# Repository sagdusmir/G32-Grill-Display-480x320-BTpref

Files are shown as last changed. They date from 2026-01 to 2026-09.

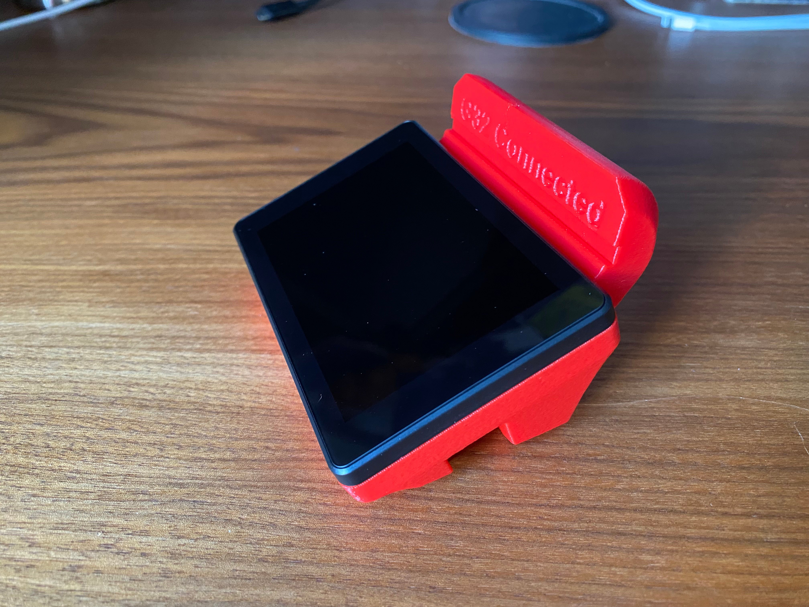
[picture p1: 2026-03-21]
misc/cases/Case JC3248W535C (remix) with mounting option to G32 or compatible modules - 7182655/images/IMG_0138.jpeg

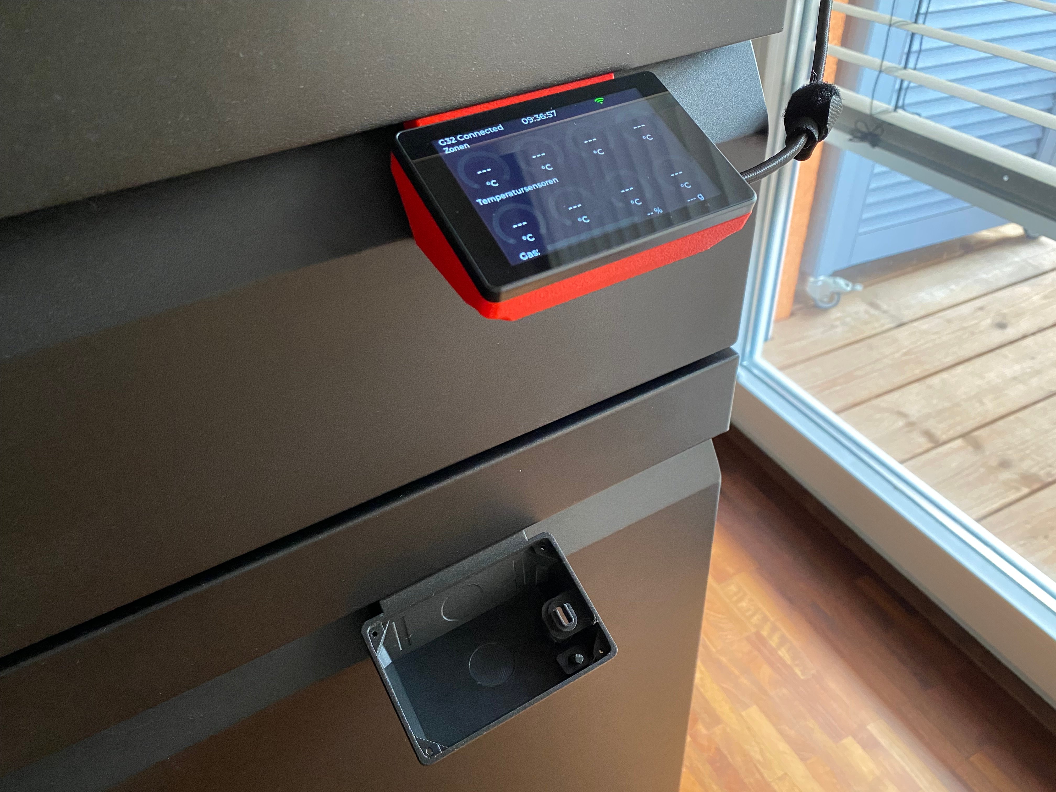
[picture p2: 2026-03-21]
misc/cases/Case JC3248W535C (remix) with mounting option to G32 or compatible modules - 7182655/images/IMG_0140.jpeg

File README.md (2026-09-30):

# G32 Connected Grill Monitor and Display








This repository started as a fork of https://github.com/JBecker32/G32-Display-480x320-BT and has since been heavily reworked with several improvements.

Focus: **mobile, cloud-independent replacement** for the official Otto Wilde app / Grill Buddy — no cloud login, no Otto Wilde servers, Home Assistant totally optional. Direct BLE connection to the grill (tested with firmware **v1.4.5**; older factory installed firmware e.g. "v13" is not compatible).

Teaser
Assembled device with the case variant for attaching it to OW Module handles.

# Table of Contents

1. [Features](#features)
   - [Implemented functionality](#implemented-functionality)  
   - [What is missing?](#what-is-missing)
   - [Limitations](#limitations)
3. [Hardware](#hardware)
   - [BOM](#bom)
   - [Component Details](#component-details)
4. [Uploading the software to the ESP](#uploading-the-software-to-the-esp)
   - [Prebuilt firmware](#prebuilt-firmware)
   - [Compile from source](#compile-from-source)
5. [FAQ](#faq)
   - [Flashing](#flashing)
   - [Usage](#usage)
6. [Impressions](#impressions)
7. [Acknowledgments](#acknowledgments)
8. [Disclaimer](#disclaimer)

## Features

### Implemented functionality

- Real-time temperatures for up to **4 grill zones** + **4 external probes**
- **Gas level** monitoring (if GasBuddy is installed)
- **Alarms** — visual + optional acoustic (buzzer/speaker) for temperature limits and timer
- **Countdown timer** with alert
- Touchscreen configuration
  - tap top-left "G32 Connected" for entering the settings screen
  - tap top-middle clock / timer to setup a countdown timer
  - tap gauges to configure a temperature alarm
- Multiple **color schemes** (predefined + easy to add your own)
- **Connection & status icons** (BLE, WiFi, lid open, light on, battery SOC)
- **Optional battery monitoring** the state of charge (SOC) of an installed internal battery can be displayed
- **Optional MEATER® integration** shows tip temperatures & battery SOC instead of G32 probes when connected. Starting with BTpref-retro2.4.6 there is an alert if temperature specs are exceeded.
- **Optional Home Assistant** connectivity that exposes most of the measurements

See [changelog.md](changelog.md).

### What is missing?
* **Meater 2 plus (aka PRO) support:** Meater 2 plus units are not supported yet
* **Gas Buddy:** calibration of a new gas bottle
* **G32 light:** setting the brightness level for turning on the light in the lid

### Limitations
* Everything that was mentioned above under [What is missing?](#what-is-missing)
* The UI might be a bit laggy at times - so touch input will take a second to have any effect. Suggestions on how to improve this further are welcome.
* Volume level of the optional buzzer / speaker is a bit low. This is the reason there is no volume control in the settings.
* Meater probes can only connect to a single device at a time. However, this does not prevent using a Meater Block.

## Hardware
### BOM

| Component | Qty | Source | Costs |
|---|-----|---|---|
| ESP32 Dev Board | 1 | Amazon, AliExpress | ~17€ - 27€ |
| Case | 1 | friend with a 3D Printer | a beer |
| Screws | 4 | hardware store, eBay, Amazon, AliExpress | ~1€ |
| Battery (optional) | 1 | Amazon, AliExpress | ~9€ | 
| Buzzer / Speaker (optional) | 1 | AliExpress, Amazon, eBay | ~2€ |
| Double-Sided mirror tape (optional)  | ? | Amazon, eBay | ~0€ |
| Connection Cable | 1 | your existing collection of cables | ~0€ |

The total cost should be around 35-40€ if you have a friend with a 3d printer. Some items might not be available individually, but only in packs of several.

### Component Details

* __ESP32 Dev Board__<br>
  You need a "__JC3248W535C__". It is equipped with an ESP32-S3, WiFi, Bluetooth, a 480x320 Pixel 3.5" touchscreen, and everything you need. No additional memory card required.

* __Case__<br>
 For a 3D model of a case for the JC3248W535C you can take a look at one of these:
   * [Case by so99hero](https://www.thingiverse.com/thing:7127557)<br>
     This nicely designed case offers enough space to fit all mentioned components and has a print-in-place mechanism to operate the power button (SW1) on the pcb.
   * [Case by so99hero (remixed by sagdusmir)](https://www.thingiverse.com/thing:7182655)<br>
     This one features minor adjustments to physically support the USB-C port and reduced clearance for the power button.<br>
     There is also a case variant that attaches directly to any front facing handles of the OW Modules which is shown in some of the images.
     If you like to have both: there is also a model that allows to hang a normal case to a OW Module handle.
   * [Case by so99hero (remixed by sagdusmir for displays prone to delamination)](https://www.thingiverse.com/thing:7295356)<br>
     This one is based on my remixed case, but features a bezel to keep the display from delaminating. The optional hanger add-on for OW Modules is also available for this model.<br>
     There is a 2nd version labeld "color-accent" that has a tiny 0.02mm recess at the front that allows you to use a Color Painting tool in your slicer ("fill" mode) and apply another filament / color to that recess.

  Note: Mounting the display to the case requires you to remove the plastic cover at the back of the display.

* __Screws__<br>
  Either M2x6mm, M2x5mm, or M2x4mm should work fine. 

* __Battery__<br>
  You can add a 3.7V LiPo/Li-Ion Battery (1 cell) with a JST 1.25 2pin connector (__watch out for correct polarity__ – see images). A capacity of 2000mAh to 3000mAh is recommended and of course it should have protection circuitry built in. This connects directly to the "BAT" (P5) connector. Maximum dimensions should not exceed 10mm x 65mm x 35mm (E.g. "103350", "103450", … "103565").

* __Buzzer / Speaker__<br>
  You can choose to connect either a buzzer or a speaker:
  * A passive piezo buzzer.<br>These do not seem to be available with a JST1.25 2pin connector. So you might need to solder a JST 1.25 2pin connector cable obtained separately to the buzzer leads. Additional work, and probably additional costs. This connects to the GPIO (P2) connector to pins IO9 and IO14. If you have a DIY JST1.25 assortment (and/or OCD), you can do a custom 8pin connector that nicely fits P2. But a 2pin connector will do fine.
  * EXPERIMENTAL: A small 8Ohm / 1W speaker (4Ohm / 3W for noisy environments) with a JST1.25 2pin connector. <br>This usually results in a slightly higher volume and a more pleasant sound. Getting one with the proper connector saves you some effort. This connects directly to the "SPEAK" (P6) connector. This is still considered "experimental" and needs some verification if the used external DAC is actually powered off if the ESP32 is powered down.

  Note: Take the available space into consideration. The passive buzzer is configured by default in the YAML. Switching to the speaker requires enabling / disabling the marked config blocks, or use a pre-configured YAML / firmware from the latest [releases](https://github.com/sagdusmir/G32-Grill-Display-480x320-BTpref/releases).

* __Cable__<br>
  Any USB-C to USB-C / USB-A with data lines will do for charging and flashing the ESP32.

* __Double-Sided mirror tape__<br>
  Use this to hold the battery and buzzer / speaker in place.

## Uploading the software to the ESP

### Prebuilt firmware

Each [GitHub Release](https://github.com/sagdusmir/G32-Grill-Display-480x320-BTpref/releases/latest) includes compiled images with placeholder Wi-Fi, OTA, and Home Assistant values. The extra `.espbinpatch` suffix is the same firmware as a `.bin` — patch those secrets, then flash. Do not flash the download as-is.

| File | When to use |
|---|---|
| `*-buzzer.factory.bin.espbinpatch` | Buzzer hardware, first flash on a new or empty board (erases everything) |
| `*-buzzer.ota.bin.espbinpatch` | Buzzer hardware, later updates if the device already works (keeps saved settings) |
| `*-speaker.factory.bin.espbinpatch` | Speaker hardware, first flash on a new or empty board (erases everything) |
| `*-speaker.ota.bin.espbinpatch` | Speaker hardware, later updates if the device already works (keeps saved settings) |

1. Download the matching file from the latest release.
2. Use the ESP Bin Patcher link in the release notes (preconfigured) in **Chrome or Edge**.
3. Choose the downloaded file on that page.
4. Fill in the replacements (Wi-Fi SSID, Wi-Fi password, OTA password, Home Assistant API key).
   For the API key, paste your Home Assistant / ESPHome `api.encryption.key` (the Base64 value) as **New**.
5. Click **Patch firmware**, connect the board via USB, then **Install patched firmware**.
   - Factory file: choose **Erase everything**.
   - OTA file: choose **Keep saved settings**.

### Compile from source

1. Install ESPHome CLI
   ```bash
   pip install esphome
   ```
2. Clone this repository and change directory into that folder
   ```bash
   git clone https://github.com/sagdusmir/G32-Grill-Display-480x320-BTpref.git && cd G32-Grill-Display-480x320-BTpref
   ```
3. Connect the JC3248W535C via USB
4. Compile and flash the software
   ```bash
   esphome run g32-display.yaml
   ```
   You may be asked how the connection should be established.

## FAQ

### Flashing

1. Easiest path: download a prebuilt `.espbinpatch` from the latest [release](https://github.com/sagdusmir/G32-Grill-Display-480x320-BTpref/releases/latest) and patch Wi-Fi / OTA / Home Assistant values in [ESP Bin Patcher](https://sagdusmir.github.io/ESP-bin-patcher/) (see [Prebuilt firmware](#prebuilt-firmware)). If you compile from source: nothing to change in the YAML if you trust everyone on the same WiFi. Everyone else: `api_encryption_key`, `ota_password`. Have a look at the very top of `g32-display.yaml` for details.

2. During validation of the yaml file, you might see something like `[max_connections] is an invalid option for [esp32_ble]`. The "max_connections" option has been moved from "esp32_ble_tracker:" to "esp32_ble:". Both variants are included in the YAML and you need to switch to the other variant by adding / removing a comment (#). Do not mess up the indentation. This is caused by a breaking change in esphome.

3. If compiling and flashing the ESP32 succeeds, but the screen is looking distorted (the left portion is partially readable while the right portion shows mostly pixel noise"), simply look at the "dimensions" in the "display" section and swap the values for "width:" and "height:". This is caused by a breaking change in esphome.

4. If you get A LOT of strange syntax errors, try to clean up the configured build folder via
   ```bash
   esphome clean g32-display.yaml
   ```

### Usage
   - How do I know the current IP address if the device is connected to WiFi? Open "Settings" and touch the tiny version text in the title bar. Next to the QR code there should be the current IP address displayed.
   - Why does the device power on if the USB power supply is removed? That is expected behavior of the used Dev-Board and happenes due to switching from USB power supply to battery power supply.
   - Why is the battery SOC incorrect if the device is powered via USB? The onboard charge contoller has no I²C interface to get any information about the supplied power and progress of charging. The shown SOC during charging is not accurate.
   - Why can the device not be powered off during charging? This is a hardware limitation of the used Dev-Board due to how charging is handled.
   - Why is my device losing battery charge when not in use? The Dev-Board seems to always draw a noticable amount of power - even if the device is shut down. There is no easy fix for that.
   - Why does the device not power off, even if I press the power button for a few seconds? Try to press the button even longer. This can take up to 14 seconds and varies from device to device.

## Impressions
<small>These images show different versions of the software - so some details might be inconsistent.</small>

device_assembly
BTpref-retro2 0 0-main_view_cyan

BTpref-retro2 0 1-main_view_red_light
BTpref-retro2 0 1-main_view_white
BTpref-retro2 0 0-main_view_amber
BTpref-retro2 0 0-temp_alarm
BTpref-retro2 0 0-timer
BTpref-retro2 0 0-mac_address
BTpref-retro2 3 0-wifi
BTpref-retro2 4 3-options
BTpref-retro2 3 1-warnings
BTpref-retro2 2 0-display
BTpref-retro2 0 0-meater
BTpref-retro2 4 3-version
BTpref-retro2 4 0-reduced-temp-alarm-info
Speaker Assortment
BTpref-retro2 4 1-battery-3000mAh
device_assembly_4ohms
In action 1
In Action 2
JC3248W535 board

## Acknowledgments
This project would not have been possible without the work of the community. Special thanks go to:

[JBecker32/G32-Display-480x320-BT](https://github.com/JBecker32/G32-Display-480x320-BT) (the original software project)

[fschwarz86/g32](https://github.com/fschwarz86/g32)

[ralmoe/g32-docker-client](https://github.com/ralmoe/g32-docker-client)

[MortenVinding/MEATER.yaml](https://gist.github.com/MortenVinding/a513c0094d0df41a4425612257b3cabc) (Meater® accuracy)

[so99hero/Standalone Case JC3248W535C](https://www.thingiverse.com/thing:7127557)

## Disclaimer
This is third-party software developed by the community and is not officially developed or supported by Otto Wilde GmbH. Use at your own risk.

__This project is provided for educational and experimental purposes only.__

All hardware designs, schematics, code, instructions, and documentation are offered AS IS without any warranty of any kind, express or implied.
YOU BUILD AND USE THIS AT YOUR OWN RISK.
The author(s) and any contributors are not responsible for any injury, death, property damage, fire, electrical shock, data loss, voided warranties, legal violations, or any other consequences — direct, indirect, incidental, or consequential — that may result from building, modifying, or using this project or any derivative work.
Always follow local electrical/safety/building codes.

If you're not experienced with mains voltage, high current, lithium batteries, lasers, moving parts, etc., consult a qualified professional before proceeding.
Proceed only if you accept full personal responsibility.

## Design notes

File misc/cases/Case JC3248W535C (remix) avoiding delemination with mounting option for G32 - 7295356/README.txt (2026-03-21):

Case JC3248W535C (remix) avoiding delemination with mounting option for G32 by sagdusmir on Thingiverse: https://www.thingiverse.com/thing:7295356

Summary:
Remixed remix case for the ESP32S3 3.5" touchscreen module JC3248W535C.Original model: https://www.thingiverse.com/thing:7127557Remixed model: https://www.thingiverse.com/thing:7182655 IF your JC3248W535C display tends to lift off the plastic carrier (due to bad adhesion), this model is for you!If not: go with one of the original designs instead. :)The ESP32 dev board module is secured with four M2x4 mm, M2x5 mm, or M2x6 mm threaded screws.There are 3 different designs available:The remix case remixed with minor changes:there is an additional bezel that clips to the ESP32 display and prevents the top display from separatingA hanger that serves as an add-on for the case  (only intended to be used with this case model because it takes the added bezel into consideration).In case you happen to own a G32 Connected gas grill, this repository might be of interest to you: https://github.com/sagdusmir/G32-Grill-Display-480x320-BTprefIMPORTANT:- Do not print with supports!- You might need to drop the bottom of the model onto the print bed in your slicer - Before installing the display, the cover plate on the back of the display must be removed!- Before tightening down the screws, check if the collar around the USB-C port causes any distress to the PCB or its components!  (the display detaches from  its mounting frame if there is any force applied from the back by the case)

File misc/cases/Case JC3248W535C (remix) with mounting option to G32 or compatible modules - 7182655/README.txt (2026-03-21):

Case JC3248W535C (remix) with mounting option to G32 or compatible modules by sagdusmir on Thingiverse: https://www.thingiverse.com/thing:7182655

Summary:
Remixed case for the ESP32S3 3.5" touchscreen module JC3248W535C.Original model: https://www.thingiverse.com/thing:7127557 If your displays tends to lift itself off the plastic carrier, check this out: https://www.thingiverse.com/thing:7295356 The ESP32 dev board module is secured with four M2x4 mm, M2x5 mm, or M2x6 mm threaded screws.There are 3 different designs available:The original case remixed with minor changes:The clearance for the button was reduced by about 0.3mm (less force required to operate the button).Added collar around the USB-C port to hold down the PCB and prevent flex if the USB-C plug is removed.The remixed case what can be hooked into any G32 Connected handles or the handles of compatible modules (this is an alternative ESP32 case)A hanger that serves as an add-on instead of a replacement for the case  (compatible with the original case or the remixed one).In case you happen to own a G32 Connected gas grill, this repository might be of interest to you: https://github.com/sagdusmir/G32-Grill-Display-480x320-BTprefIMPORTANT:- Do not print with supports!- You might need to drop the bottom of the model onto the print bed in your slicer - Before installing the display, the cover plate on the back of the display must be removed!- Before tightening down the screws, check if the collar around the USB-C port causes any distress to the PCB or its components!  (the display detaches from  its mounting frame if there is any force applied from the back by the case)Updates2026-02-12 The case with the included hanger has been updated for easier printing and offers slightly more space for internal components.

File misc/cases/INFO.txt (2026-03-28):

This is a BACKUP of my case models on Thingiverse in case the platform goes the way of the Dodo.

Please always give preference to the online versions and only see this as a fallback.

Printing instructions: All 3D models in this repo can be printed whithout support. Orient the bottom (for the bezel model only: the top) on the build plate and you should be good to go.

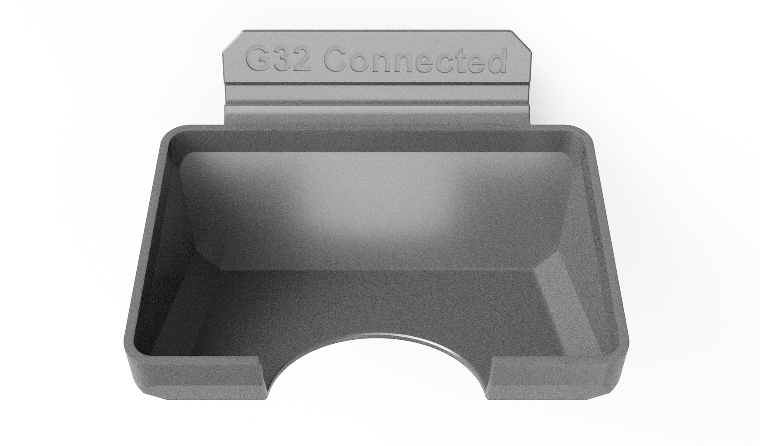
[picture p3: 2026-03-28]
misc/cases/Case JC3248W535C (remix) with mounting option to G32 or compatible modules - 7182655/images/Case_JC3248W535C_optional_hanger.jpg

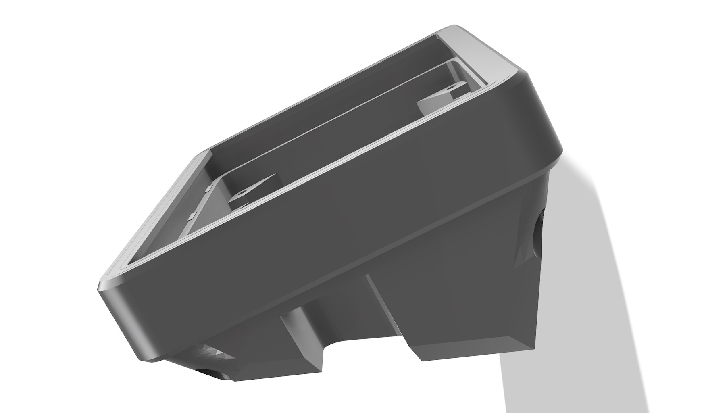
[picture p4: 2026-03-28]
misc/cases/Case JC3248W535C (remix) avoiding delemination with mounting option for G32 - 7295356/images/Case_JC3248W535C_for_use_with_bezel.jpg

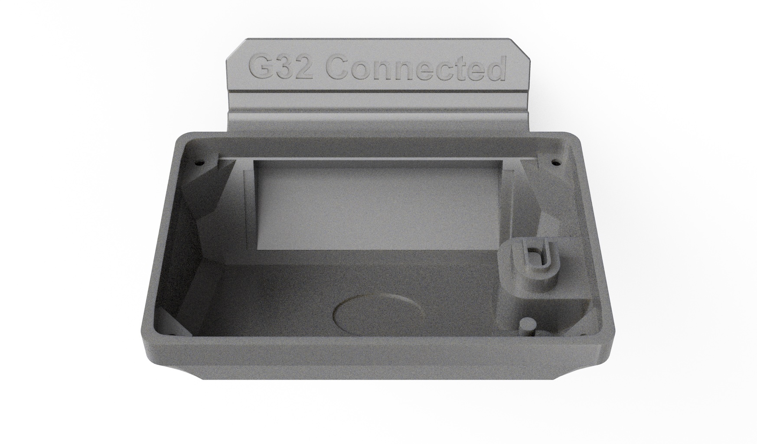
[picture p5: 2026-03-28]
misc/cases/Case JC3248W535C (remix) with mounting option to G32 or compatible modules - 7182655/images/Case_JC3248W535C_for_G32_-_gravity_hanger.jpg

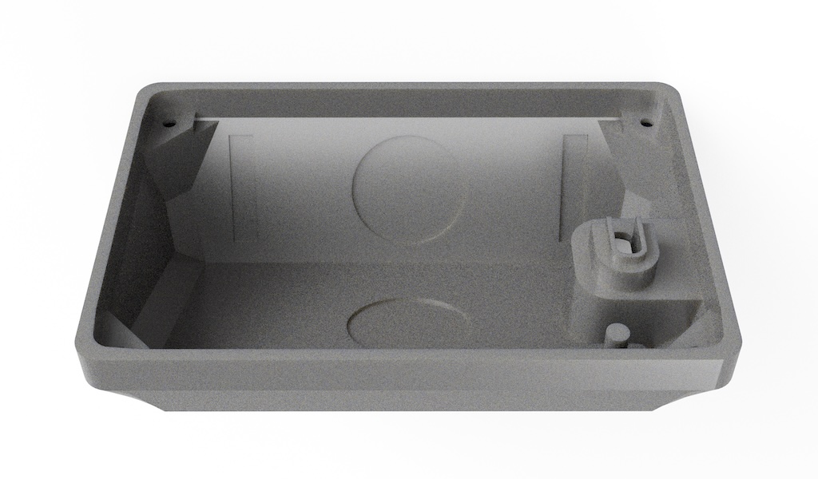
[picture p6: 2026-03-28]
misc/cases/Case JC3248W535C (remix) with mounting option to G32 or compatible modules - 7182655/images/Case_JC3248W535C_mod.jpg

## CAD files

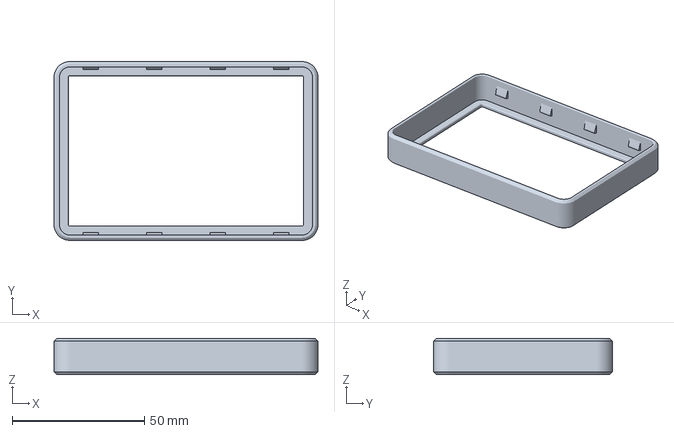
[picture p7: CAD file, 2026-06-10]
misc/cases/Case JC3248W535C (remix) avoiding delemination with mounting option for G32 - 7295356/files/Case_JC3248W535C_bezel-color-accent.3mf
99.8 x 67.6 x 13.7 mm

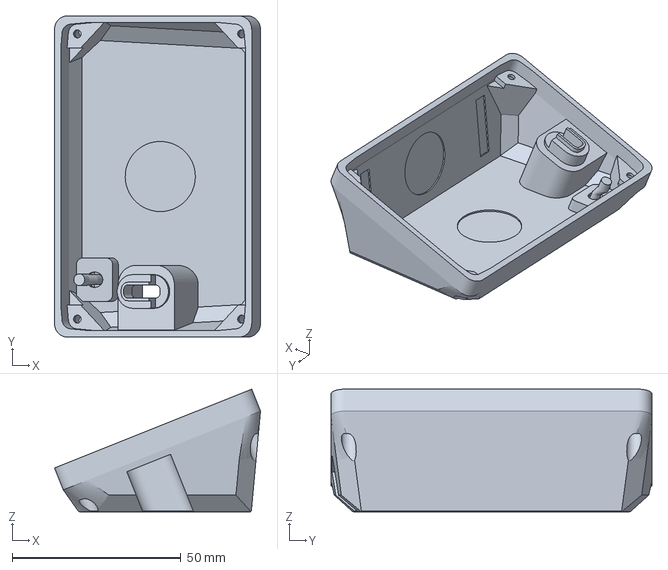
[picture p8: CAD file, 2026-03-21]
misc/cases/Case JC3248W535C (remix) with mounting option to G32 or compatible modules - 7182655/files/Case_JC3248W535C_mod.3mf
61.1 x 95.2 x 36.4 mm

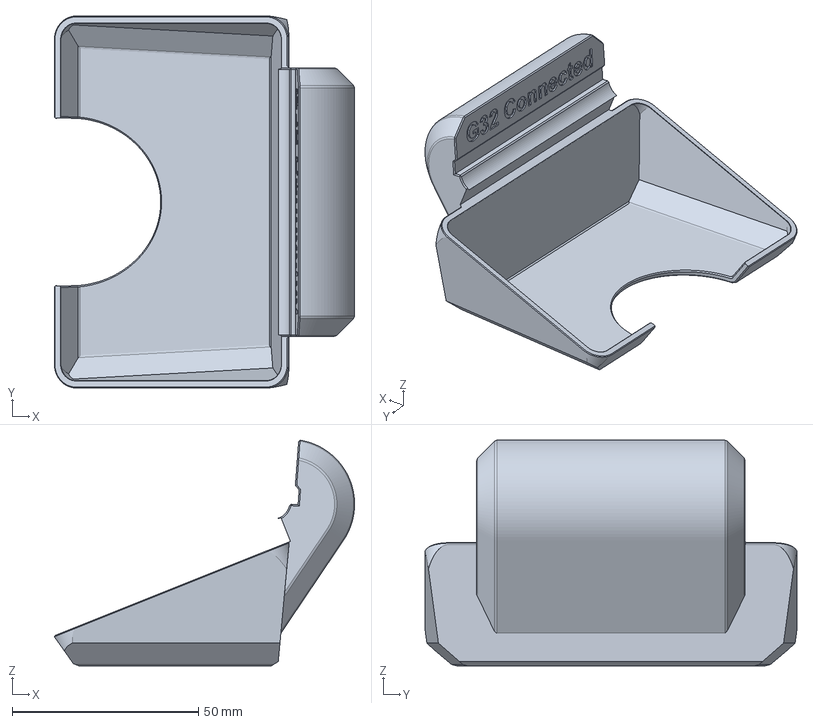
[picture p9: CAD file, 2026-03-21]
misc/cases/Case JC3248W535C (remix) avoiding delemination with mounting option for G32 - 7295356/files/Case_JC3248W535C_with_bezel_optional_hanger.3mf
80.5 x 99.8 x 60.5 mm

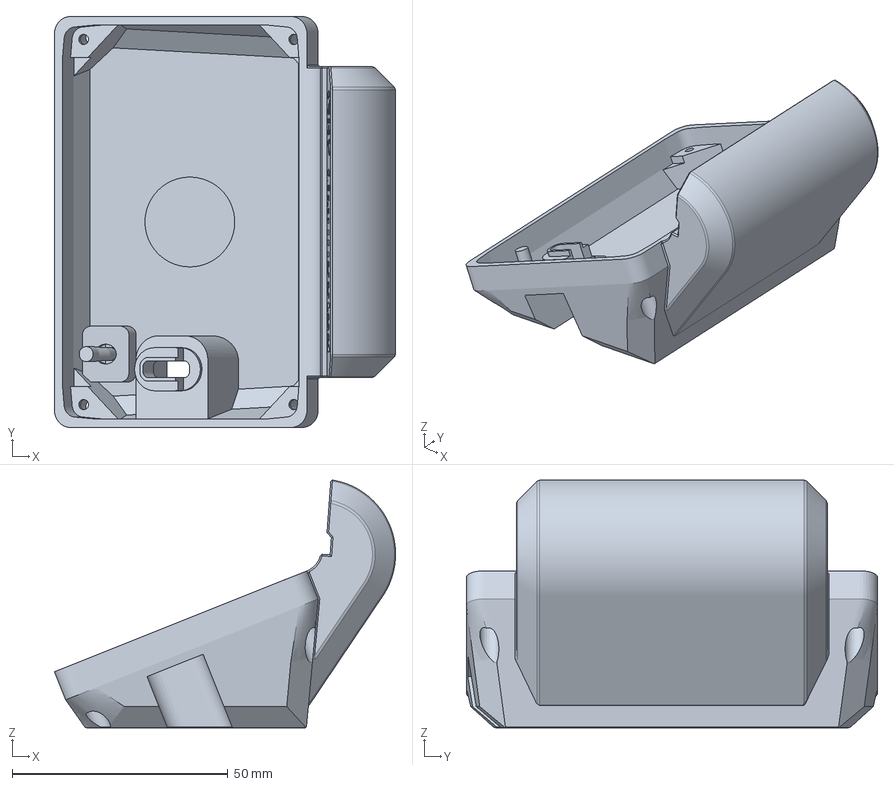
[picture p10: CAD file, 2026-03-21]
misc/cases/Case JC3248W535C (remix) with mounting option to G32 or compatible modules - 7182655/files/Case_JC3248W535C_for_G32_-_gravity_hanger.3mf
79.0 x 95.2 x 57.4 mm

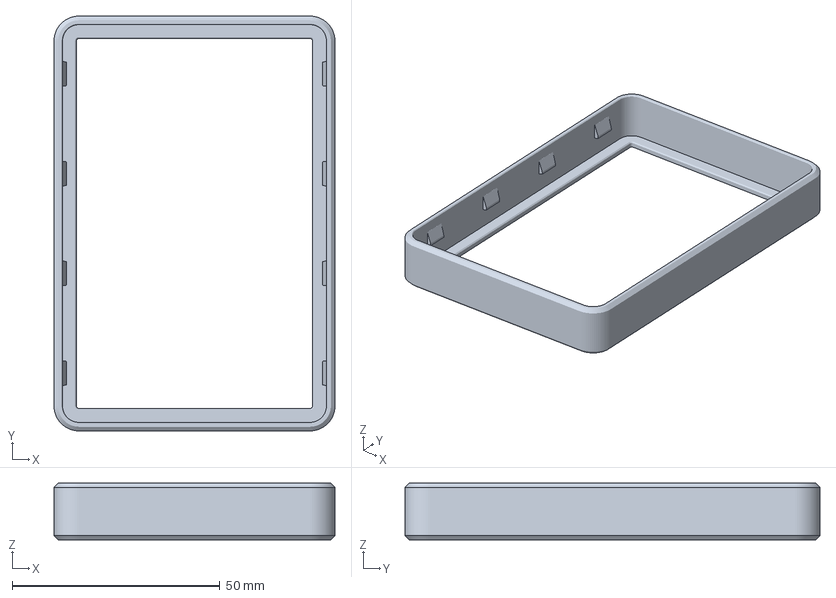
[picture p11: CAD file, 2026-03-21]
misc/cases/Case JC3248W535C (remix) avoiding delemination with mounting option for G32 - 7295356/files/Case_JC3248W535C_bezel.3mf
67.6 x 99.8 x 13.7 mm

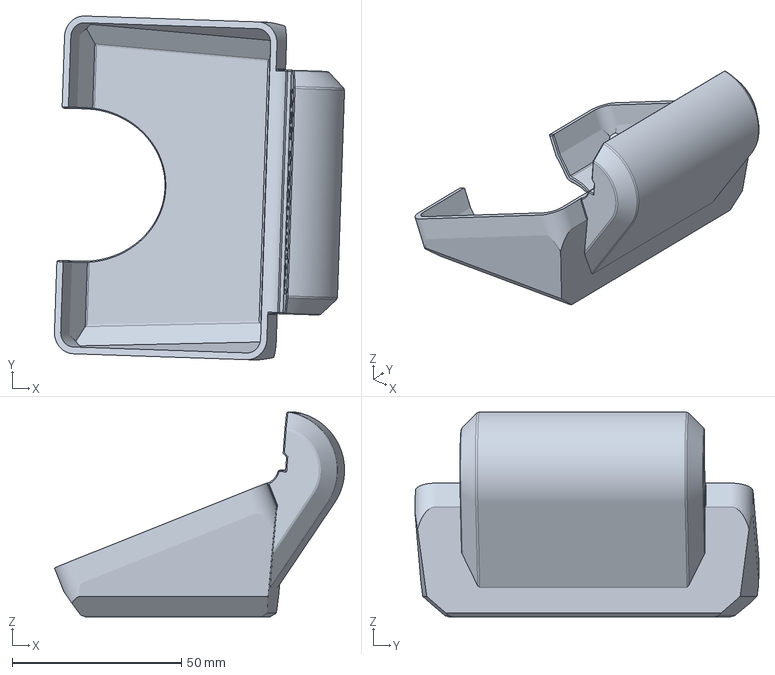
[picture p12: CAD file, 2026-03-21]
misc/cases/Case JC3248W535C (remix) with mounting option to G32 or compatible modules - 7182655/files/Case_JC3248W535C_optional_hanger.3mf
85.7 x 101.6 x 60.5 mm

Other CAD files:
misc/cases/Case JC3248W535C (remix) avoiding delemination with mounting option for G32 - 7295356/files/Case_JC3248W535C_for_use_with_bezel.3mf
misc/cases/Case JC3248W535C (remix) avoiding delemination with mounting option for G32 - 7295356/files/Case_JC3248W535C_bezel-color-accent.stl
misc/cases/Case JC3248W535C (remix) avoiding delemination with mounting option for G32 - 7295356/files/Case_JC3248W535C_bezel.stl
misc/cases/Case JC3248W535C (remix) avoiding delemination with mounting option for G32 - 7295356/files/Case_JC3248W535C_for_use_with_bezel.stl
misc/cases/Case JC3248W535C (remix) avoiding delemination with mounting option for G32 - 7295356/files/Case_JC3248W535C_with_bezel_optional_hanger.stl
misc/cases/Case JC3248W535C (remix) with mounting option to G32 or compatible modules - 7182655/files/Case_JC3248W535C_for_G32_-_gravity_hanger.stl
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

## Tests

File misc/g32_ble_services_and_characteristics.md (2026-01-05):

# BLE Services and Characteristics scan

Device OWG-G32C-XXXXXXXX

- Service Device Information (0x1800)
  - Model Number String (ØxZA24) [Read]
  - Serial Number String (ØxZA25) [Read]
  - Firmware Revision String (0xZA26) [Read]
  - Manufacturer Name String (OxZA29) [Read]
  - 5f8b9bdØ-86f7-4c68-9dce-3d1d4cb21b95 [Read]
  - 5f8b9bda-86f7-4c68-9dce-3d1d4cb21b95 [Read]
  - 5f8b9bdb-86f7-4c68-9dce-3d1d4cb21b95 [Read, Write]
  - 5f8b9bdc-86f7-4c68-9dce-3d1d4cb21b95 [Read, Notity]

- Service Environmental Sensing (Øx1800)
  - Temperature Measurement (ØxZA1C) [Read, Notify]
  - 1f168db0-72ba-4806-84cc-e1c310898566 [Read, Write]
  - 1f168db1-72ba-4806-84cc-e1c310898566 [Read, Write]
  - 1f168db2-72ba-4806-84cc-e1c310898566 [Read]
  - 1f168db3-72ba-4806-84cc-e1c310898566 [Read, Notifyl
  - 1f168db4-72ba-4806-84cc-e1c310898566 [Read, Write, Notify]

- Service Weight Scale (0x1800)
  - Body Composition Feature (0xZA9D) [Read, Notify]
  - Body Composition Control Point (ØxZA9E) [Write]
  - 64ebc8a3-e9a4-11ed-a05b-0242ac120003 [Write]
  - 64ebc8a4-e9a4-11ed-a05b-0242ac120003 [Write]
  - 64ebc8a5-e9a4-11ed-a05b-Ø242ac120003 [Read, Notify]
  - 64ebc8a6-e9a4-11ed-a05b-0242ac120003 [Write]
  - 64ebc8a7-e9a4-11ed-a05b-0242ac120003 [Read]
  - 64ebc8a8-e9a4-11ed-a05b-0242ac120003 [Read]
  - 64ebc8a9-e9a4-11ed-a05b-0242ac120003 [Read, Notify]

- Service e1255ec0-6199-44ab-b78e-08ec262cea4b
  - e1255ec0-6199-44ab-b78e-Ø8ec262cea4b [Read, Notify]
  - e1255ec1-6199-44ab-b78e-08ec262cea4b [Read, Notify]
  - e1255ec2-6199-44ab-b78e-08ec262cea4b [Read, Write, Notify]

- Service 64cd0d41-2f66-4e6f-b1af-fac03a604018
  - 64cd0d41-2f66-4e6f-b1af-fac03a604018 [Read, Write, Notify]
  - 64cd0d42-2f66-4e6f-b1af-fac03a604018 [Write]
  - 64cd0d43-2f66-4e6f-b1af-fac03a604018 [Read, Write, Notify]

- Service 830eØ2f5-843b-49c3-a4fa-613587247e6c
  - 830e02f5-843b-49c3-a4fa-613587247e6c [Write]
  - 830e02f6-843b-49c3-a4fa-613587247e6c [Read]
  - 830e02f7-843b-49c3-a4fa-613587247e6c [Read, Write]

- Service dc0f41e1-b6ae-46a8-а19e-1a3bf4342bcb
  - dc0f41e1-b6ae-46a8-a19e-1a3bf4342bcb Write]
  - dc0f41e2-b6ae-46a8-a19e-1a3bf4342bcb [Read, Notify]

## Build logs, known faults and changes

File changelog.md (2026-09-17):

# Changelog
* [2026-09-17] BTpref-retro 2.5.7-1

* [2026-09-13] BTpref-retro 2.5.7
   - meater tip temperature reading now supports frozen steaks
* [2026-09-13] BTpref-retro 2.5.6
   - updated for esphome 2026.8.x compatibility
* [2026-07-21] BTpref-retro 2.5.5
   - minor fix: check for g32_firebox_open
* [2026-07-05] BTpref-retro 2.5.4
   - typo: „Firebox“ in HA
* [2026-06-23] BTpref-retro 2.5.3
   - fix: HomeAssistant Meater unit label
   - fix: move gas weight symbol in the bottom right to better match the orientation of the gas bottle symbol
   - add 3d model with color accent on the front bezel
   - seems compatible with latest esphome 2026.6.x
* [2026-04-18] BTpref-retro 2.5.2
   - BREAKING!! updated for esphome 2026.4.0 compatibility
   - e.g. screen and touchscreen configuration (fix), cpu speed (keep old setting), tab bar color scheme update (broken due to lvgl 9.x update)
   - fix timer page for lvgl 9.x
* [2026-03-29] BTpref-retro 2.5.0
   - add to HA: Softare Version
   - change for HA: BT Signalstärke -> BT Signal Level
   - change for HA: WiFi Signal ESP G32 -> WiFi Signal ESP
   - change for HA: Temperatur ESP G32 -> CPU Temperature ESP
   - change for HA: G32 Gasbuddy level in % -> G32 Gasbuddy Level in %
   - change HA Status ESP G32 -> Status ESP
* [2026-03-13] BTpref-retro 2.4.12
   - minor tweaks
   - testing stability improvements
* [2026-03-13] BTpref-retro 2.4.11
   - fix: latest version check (buffer to small)
   - show wifi IP address
* [2026-03-05] BTpref-retro 2.4.10
   - rollback of some core pinning that introduced weird behavior
* [2026-02-20] BTpref-retro 2.4.9
   - updated compatibility to esphome 2026.2.0
   - add small icon if countdown timer is enabled or active
* [2026-02-16] BTpref-retro 2.4.8
   - release should now contain yaml artifacts for buzzer / speaker
   - fix: silence warning sign in the first seconds after boot
* [2026-02-07] BTpref-retro 2.4.7
   - removed ntp servers altogether (thanks @JBecker32, and @fschwarz86 for pointing that out)
   - bugfix: color schemes with dedicated color for icon and text shadows
   - new color scheme "white (clean)" that demonstrates setting the icon and text shadows to black
* [2026-02-02] BTpref-retro 2.4.6
   - new alerts if Meater reading exceeds specification (tip: 100°C, ambient: 275°C)
   - color themes now have a dedicated color for shadows of symbols and text
   - all shadows of symbols and text can be forced to black by using a new substitution FORCE_SHADOW_COLOR_TO_BLACK
* [2026-02-01] BTpref-retro 2.4.5
   - hotfix: switch sntp servers for getting the accurate daytime
* [2026-01-29] BTpref-retro 2.4.4
   - bugfix: solo Meater reports 0 instead of the probe ID
* [2026-01-28] BTpref-retro 2.4.3
   - option to hide gas buddy readings
* [2026-01-28] BTpref-retro 2.4.2
   - minor UI tweaks and possibly performance inprovements
* [2026-01-21] BTpref-retro 2.4.1
   - configuration to make use of the speaker header and the external DAC for nicer and slightly louder audio
* [2026-01-11] BTpref-retro 2.4.0
   - reduced UI with increased temperature font size if temperature alarms are disabled
   - new option in settings: "dynamic temp. warning info"
     will automatically switch between old UI and reduced UI depending on if a temperature alarm was configured (disabled by default).
   - bugfix: scanning for meater probes does not reset all mac addresses any more
* [2025-12-19] BTpref-retro 2.3.3
   - gas level indicator bar segmentation now makes sense
* [2025-12-14] BTpref-retro 2.3.2
   - more color schemes
* [2025-12-12] BTpref-retro 2.3.0
   - allow configuring the OTA password in the settings
* [2025-12-09] BTpref-retro 2.2.0
   - color scheme can now be selected in the settings without changing the source code
* [2025-12-06] BTpref-retro 2.1.1
   - load font files from github - so now the software is only a single yaml file again
* [2025-12-04] BTpref-retro 2.1.0
   - updates for ESPHome 2025.11.3
   - automatic version check
* [2025-11-30] BTpref-retro 2.0.4
   - enable warning sign when gas tank level / soc level is low
* [2025-11-28] BTpref-retro 2.0.1
   - retro style
   - combine numbers and arcs into a single view
   - overall improved touch sensitive areas / usability 
   - ability the easily change color theme (requires flashing the device)
* [2025-11-26] BTpref 1.6.8
   - fixes for G32 reconnect
   - fixes for HA values (especially decimal places)
* [2025-11-12] BTpref 1.6.7
   - usability if WiFi password configuration improved
   - revised Meater configuration page
* [2025-11-06] BTpref 1.6.6
   - delete individual Meater MAC addresses by touching the respective address
* [2025-10-28] BTpref 1.6.5
   - improved Meater accuracy
   - Meater battery level is now shown in the arc view
* [2025-10-24] BTpref 1.6.0
   - Meater support (Meater "Plus" should also work)
* [2025-10-23] BTpref 1.5.4
   - visual hint when G32 MAC scan was successful
* [2025-10-20] BTpref 1.5.3
   - typo in the WiFi settings UI
* [2025-10-19] BTpref 1.5.2
   - fixed position status bar top/bottom
   - countdown timer combined with optional clock display (top center)
   - new UI for setting temperature alarms
   - on-device configuration screen available via the "G32 Connected" text in the top status bar
   - HA integration is now fully optional but still available

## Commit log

2025-06-30 Update g32-display.yaml
    Wrong closing curly bracket removed!
2025-07-11 Update g32-display.yaml
    correct wrong color setting for sensor2_arc
2025-07-11 Update README.md
    diverse kleine Änderungen in der Beschreibung
2025-08-29 Update g32-display.yaml to V1.1.0c
    bug fix Zone 1 and 2 temperatures were not masked to valid range
2025-09-03 Update README.md
    added bill of material
2025-09-07 Update g32-display.yaml to V1.3.0
    - bug fixes
    - timer added
    - ...
2025-09-07 Update README.md to V1.3.0
    - added timer
2025-09-09 Update g32-display.yaml to V1.31
    - timer is now working independantly from the RTC (HA or SNTP)
    - it is so easy, why not from the start ...
2025-09-24 Update g32-display.yaml to V1.4.0
    - changed display driver platform to 'mipi_spi'
    - design changes on timer and limits page
    - more configuration options
    - minor changes
2025-10-19 feature/on-device-configuration
    commit 9a9b521dd09adec28eb67409c75ce20593f60dcd
    Author: Jens <jens@michlo.de>
    Date: Sun Oct 19 07:15:43 2025 +0200
    some cleanup and visibility fixes
    commit f605fd8a7751455744ca3f627cef2c7e23555fc8
    Author: Jens <jens@michlo.de>
    Date: Sun Oct 19 06:18:09 2025 +0200
    settings for wifi credentials
    commit 96b86a5097d2b01dbbf271d1e8283fce273975e1
    Author: Jens <jens@michlo.de>
    Date: Sat Oct 18 21:03:57 2025 +0200
    wip
    commit b69b877e4a71d11ef0c19a48787d987ffc85e030
    Author: Jens <jens@michlo.de>
    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
2025-10-24 support meater probes
    commit fb0fc047c0938e4cbae0e900f5957690c102980f
    Date: Fri Oct 24 15:29:08 2025 +0200
    aupdate readme
    commit 280b4e590d7a7d365421faaf9e41c316631a743a
    Date: Fri Oct 24 15:21:29 2025 +0200
    also dicover meater plus probes
    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
2025-10-24 Clarify MEATER® sensor temperature description
2025-10-28 Add timer image to README impressions
2025-10-28 meater battery level and accuracy
    commit 761800915272e0a58cd928e731ba76607ece2ee5
    Date: Tue Oct 28 17:47:37 2025 +0100
    version bump
    commit 57a52a7f4a09851daf19b21787ae21142b75486f
    Date: Tue Oct 28 17:45:14 2025 +0100
    add meater battery lvel to arc page
    commit bec05664dfbb573b4f2d5d24561d8450ae33933a
    Date: Tue Oct 28 07:59:49 2025 +0100
    fix meater accuracy
    commit 20f03f44749c4d6d37f2e48767e3f3ce25549a72
    Date: Mon Oct 27 17:46:09 2025 +0100
    fetch meater battery level
    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
2025-11-01 fix: time / timer disappearing depending on rendering width
2025-11-14 minor: do not start with 0% meater battery level after connecting
2025-11-18 revert changes on „light on“ indicator
2025-11-18 all temperatures with 1 decimal accuracy
2025-11-24 english readme
    The device has been sold in other countries, too. As a consequence the UI will slowly transition to english.
2025-11-25 fix: do nit hide zone temperature labales on disconnect
2025-11-25 fix: do not hide zone temperature labales on disconnect
2025-11-26 update visualization of temp probe values
2025-11-27 position meater battery icons
2025-11-27 exit countdown timer page by click on time label
2025-11-28 minor layout fix on countdown timer page
2025-11-28 fix button shadow
2025-12-03 Update countdown timer text in g32-display.yaml
2025-12-17 Enhance README with case variant details
    Updated the README to include additional information about the remixed case variant.
2025-12-31 Update README with more details on remixed case
    Expanded description of the remixed case to include additional model information.
2026-01-01 disable logging to reduce power consumption
2026-01-12 Update README with details on UI behavior change
    Clarified the behavior of the dynamic temperature warning info feature.
2026-01-21 Add 3000mAh battery image to README
2026-02-01 hotfix: switch sntp servers because the old ones are unavailable
2026-02-02 Update MEATER® section with alert details
    Added alert information for MEATER® temperature specifications.
2026-02-04 Fix formatting of battery option in README
2026-02-07 reworked README
    - BOM
    - component details
    - images
2026-02-07 Enhance case variant description in README
    Clarified the description of the case variant for OW Modules.
2026-02-07 Fix typo in case model reference in README
2026-02-07 Add double-sided mirror tape requirement to README
    Added information about double-sided mirror tape for battery and speaker placement.
2026-02-07 Update buzzer and speaker connection instructions
    Clarified connections for buzzer and speaker options, including custom connector details.
2026-02-07 Update README
    Clarified the option for a custom 8 pin connector for the buzzer.
2026-02-08 Update case description for USB-C adjustments
    Clarified the description of the case adjustments for USB-C support.
2026-02-16 Squashed commit of the following:
    commit fcaccb2b579d64bc0d6eb1e46686dc61e1a89ccb
    Date: Sun Feb 15 11:21:54 2026 +0100
    fix: silence warning sign at startup
    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
2026-02-21 feature/countdown-timer-indicator
    - add icon to indicate countdown timer (if not disabled)
2026-03-07 disable watchdog timers to prevent reboot
2026-03-21 add the thingiverse models…just in case something goes south
    [Case_JC3248W535C_bezel.3mf, Case_JC3248W535C_bezel.stl, Case_JC3248W535C_for_G32_-_gravity_hanger.3mf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]
2026-03-29 Update FAQ with power button press duration
    Added explanation for power button functionality.
2026-03-29 HA update: minor chnages to fix language inconsistencies. This might require updating your HA stuff. :(
    - add to HA: Softare Version
    - change for HA: BT Signalstärke -> BT Signal Level
    - change for HA: WiFi Signal ESP G32 -> WiFi Signal ESP
    - change for HA: Temperatur ESP G32 -> CPU Temperature ESP
    - change for HA: G32 Gasbuddy level in % -> G32 Gasbuddy Level in %
    - change HA Status ESP G32 -> Status ESP
2026-03-29 remove huggingface setup - it’s a bag of hurt
2026-04-03 Add image for JW3248W535 board to README
2026-04-03 Update image source for JW3248W535 board
2026-04-03 add JC3248W535 board image
2026-04-18 fix lvgl 9.x bug that prevented the timer page to show
    - fix timer page for lvgl 9.x
2026-04-20 fix: add missing label in HA to Meater Battery SOC readings
2026-06-10 add alternative 3d model for a bezel that can have a color accent
    [Case_JC3248W535C_bezel-color-accent.3mf, Case_JC3248W535C_bezel-color-accent.stl]
2026-07-05 version bump
    - typo: „Firebox“ in HA
2026-09-13 bugfix/meater-nagative-values
    - meater tip temperature reading now supports frozen steaks
2026-10-10 feature/improved-ble-dataframe-parsing
    - rewrite code for reading the BLE data frame
    - read additional BLE characteristics beyond the 32 bytes we get from the G32
    - expos additional values to HA
    - minor refinements of HA values
2026-10-10 update wirkflow to include project hint
2026-10-11 Add Home Assistant Device image to README
    Added an image for the Home Assistant Device to the README.
2026-10-11 feature/speaker-volume-in-HA
    - new volume setting in HA if the „speaker“ variant is used (uses the same „variant“ comment at the end of the line)
    - add final findings about using the speaker (discouraged if powered by battery)
    - minor cleanup
2026-10-11 Revise speaker details for external power usage
    Updated speaker section to clarify usage with external power source and potential noise issues.
2026-10-20 Add ping-pong image for Home Assistant device page
    Added an image for Home Assistant device page with controls, sensors, and diagnostics.
